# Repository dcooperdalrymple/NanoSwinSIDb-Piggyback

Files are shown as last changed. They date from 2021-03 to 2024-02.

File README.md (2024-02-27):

# NanoSwinSIDb-Piggyback

Have a faulty 6581/8580 SID chip and need a replacement? The Nano SwinSIDb is a great (though I will admit, not best) choice, but it has one fatal flaw: lack of paddle support. Using this revision on the original Nano SwinSIDb design, you can "piggyback" your original SID chip with a faulty audio circuit and use some of it's secondary functions to add back in support for reading analog paddle inputs, external audio input, and random number generator while synthesizing music using the tried-and-true Nano SwinSIDb circuit.



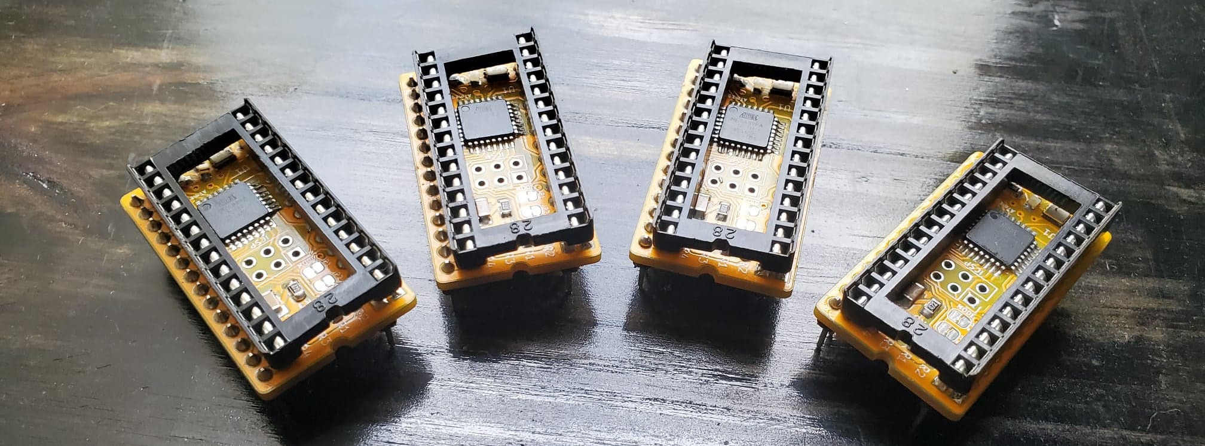
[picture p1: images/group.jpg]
Group of Nano SwinSIDb Piggybacks


## Building
The majority of the components are small SMD parts, but almost all of them can be hand-soldered with a steady hand. The only component that must be soldered using solder paste and a rework station is the active clock chip in a 3.2mm x 2.5mm package. Ensure you double check that no pads are bridged before soldering on the last part, the DIP-28 socket for the SID, because it will cover up a part of the board.

The same jumpers are provided as the original nano SwinSIDb for filter type (MOS6581/MOS8580) and output level (high/low). The jumpers are on by default to use a MOS6581 filter and have high output. You can cut them using an exacto knife to change the settings.

I use PCBWay to manufacture my boards, and all of the necessary files are provided that will be compatible with their services.

<p float="left">
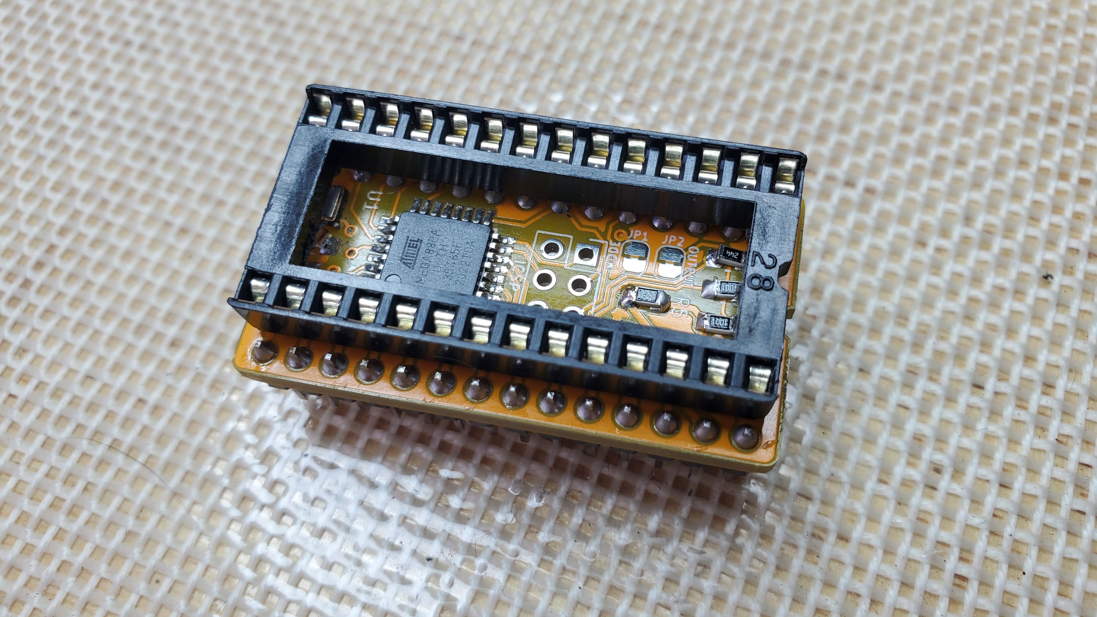
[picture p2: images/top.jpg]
Top of Nano SwinSIDb Piggyback

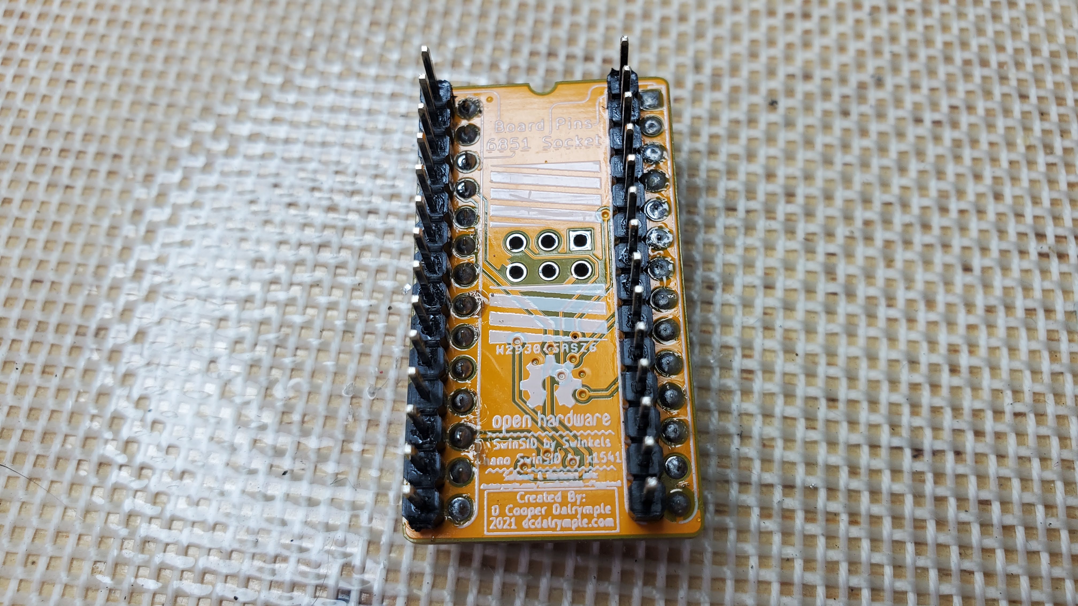
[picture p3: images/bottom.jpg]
Bottom of Nano SwinSIDb Piggyback

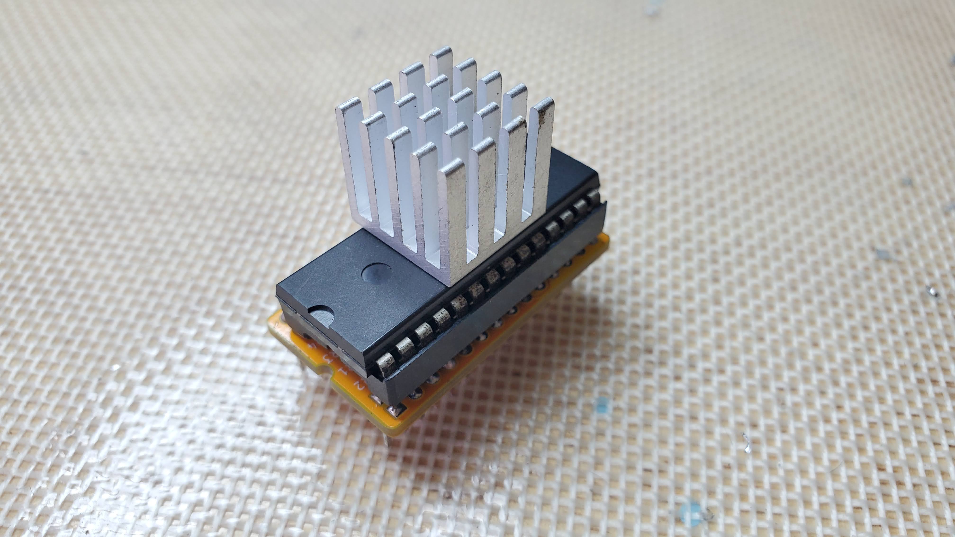
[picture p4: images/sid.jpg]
Nano SwinSIDb Piggyback with MOS6581 on Top

</p>

## Programming Firmware
A standard 6-Pin AVR ICSP header is provided on this board layout unlike the original Nano SwinSIDb. You shouldn't have to solder on a male pin header to program the board. Instead, I use a simple 6-pin cable from my programmer with a male end on it and hold it in place while flashing the chip.

Use the command `make flash` within the firmware directory to flash the copy of the SwinSID firmware with the ['Lazy' fix by Code Killer](http://www.forum64.de/index.php?thread/56605-nano-swinsid-upgrades-paddles-etc/&pageNo=2). Follow this by `make fuse` to ensure that the chip is configured correctly. The makefile utilizes avrdude with an Arduino ISP programmer on port `/dev/ttyACM0` _(linux environment)_. If this configuration doesn't work for you, either modify the Makefile or use your own flash programming environment to flash the provided firmware hex file or any other SwinSID compatible firmware.

## Additional Information
More information about building and programming your own board can be found at [tolaemon.com/nss](http://www.tolaemon.com/nss/). Most of the same principles should apply just with a few different parts. If you'd like to purchase one of these pre-built, I may have some available on my website, [dcdalrymple.com/NanoSwinSIDb-Piggyback/](https://dcdalrymple.com/NanoSwinSIDb-Piggyback/).

## Resources
- [SwinSID Analog Controller Hack](https://ilesj.wordpress.com/2014/07/24/swinsid-analog-controller-hack/)
- [nano SwinSIDb Tutorial](http://www.tolaemon.com/nss/)

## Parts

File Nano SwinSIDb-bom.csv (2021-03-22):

Source | /home/ogrecooper/repos/NanoSwinSIDb-Piggyback/Nano SwinSIDb.sch
Kicad Rev | Eeschema 5.1.9+dfsg1-1
Generated Date | Thu 04 Mar 2021 03:28:03 PM CST
Title | Not Set
Company | Not Set
Revision | Not Set
Date Issue | Not Set
Reference | Value | Library | Library Ref
U1 | ATmega88PA-AU | MCU_Microchip_ATmega | ATmega88PA-AU
JP1 | ModeSelect | Jumper | SolderJumper_2_Bridged
D1 | Yellow | Device | LED
J5 | 6PinConnector | Connector | Conn_01x06_Female
C1 | 100nF | Device | CP
X1 | ECS-3225MV | Oscillator | ECS-2520MV-xxx-xx
R6 | 330 | Device | R_Small
TP1 | TestPoint | Connector | TestPoint
TP2 | TestPoint | Connector | TestPoint
TP3 | TestPoint | Connector | TestPoint
R1 | 1k | Device | R_Small
R2 | 240k | Device | R_Small
R4 | 2.2k | Device | R_Small
R5 | 4.7k | Device | R_Small
R3 | 1k | Device | R_Small
JP2 | OutputVoltage | Jumper | SolderJumper_2_Bridged
U3 | 6581 Socket | Nano-SwinSIDb-rescue | 6581-65xx
U2 | 6581 Pins | Nano-SwinSIDb-rescue | 6581-65xx

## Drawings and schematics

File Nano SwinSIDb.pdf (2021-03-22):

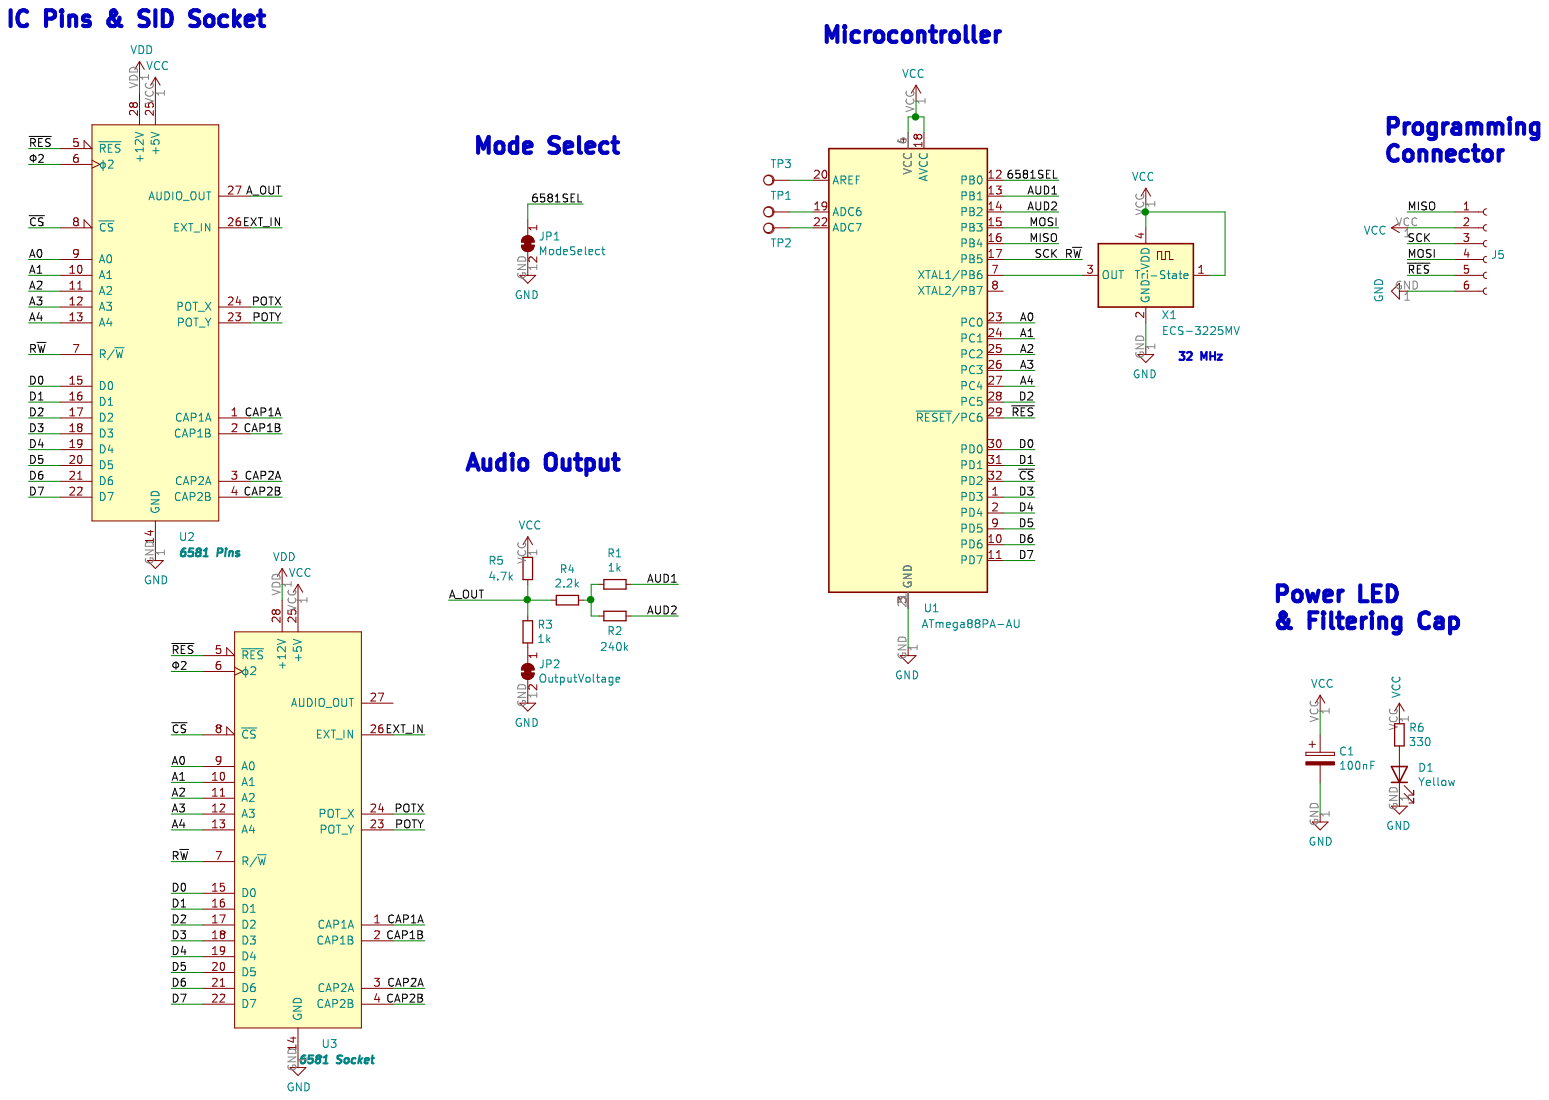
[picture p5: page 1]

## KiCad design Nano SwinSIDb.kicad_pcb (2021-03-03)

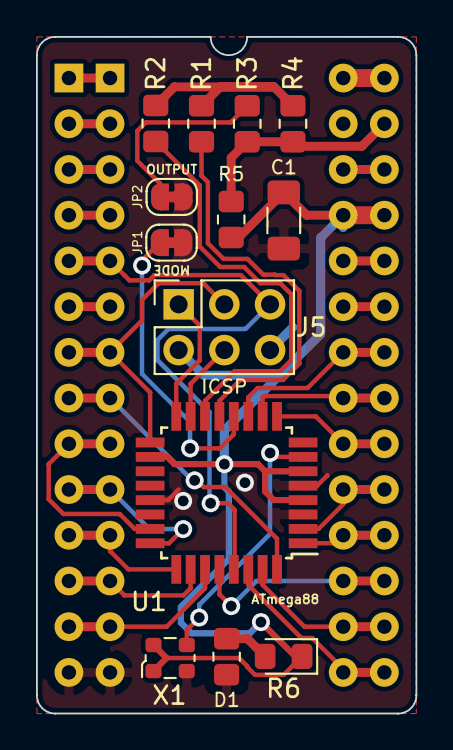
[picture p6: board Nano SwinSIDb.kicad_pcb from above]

Board: 2 copper layers, 21.1 x 37.6 mm, 15 parts (0 on the bottom side), 37 nets.

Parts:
C1: 100nF; C_1206_3216Metric_Pad1.33x1.80mm_HandSolder
D1: Yellow; R_0805_2012Metric_Pad1.20x1.40mm_HandSolder
J5: 6PinConnector; PinSocket_2x03_P2.54mm_Vertical
JP1: ModeSelect; SolderJumper-2_P1.3mm_Bridged_RoundedPad1.0x1.5mm
JP2: OutputVoltage; SolderJumper-2_P1.3mm_Bridged_RoundedPad1.0x1.5mm
R1, R3: 1k; R_0805_2012Metric_Pad1.20x1.40mm_HandSolder
R2: 240k; R_0805_2012Metric_Pad1.20x1.40mm_HandSolder
R4: 2.2k; R_0805_2012Metric_Pad1.20x1.40mm_HandSolder
R5: 4.7k; R_0805_2012Metric_Pad1.20x1.40mm_HandSolder
R6: 330; LED_0805_2012Metric_Pad1.15x1.40mm_HandSolder
U1: ATmega88PA-AU; TQFP-32_7x7mm_P0.8mm
U2: 6581 Pins; DIP-28_W15.24mm
U3: 6581 Socket; DIP-28_W15.24mm_Socket
X1: ECS-3225MV; Oscillator_SMD_ECS_2520MV-xxx-xx-4Pin_2.5x2.0mm

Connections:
/6581SEL: JP1.1, U1.12
/A0: U1.23, U2.9, U3.9
/A1: U1.24, U2.10, U3.10
/A2: U1.25, U2.11, U3.11
/A3: U1.26, U2.12, U3.12
/A4: U1.27, U2.13, U3.13
/AUD1: R1.1, U1.13
/AUD2: R2.2, U1.14
/A_OUT: R3.1, R4.2, R5.2, U2.27
/CAP1A: U2.1, U3.1
/CAP1B: U2.2, U3.2
/CAP2A: U2.3, U3.3
/CAP2B: U2.4, U3.4
/D0: U1.30, U2.15, U3.15
/D1: U1.31, U2.16, U3.16
/D2: U1.28, U2.17, U3.17
/D3: U1.1, U2.18, U3.18
/D4: U1.2, U2.19, U3.19
/D5: U1.9, U2.20, U3.20
/D6: U1.10, U2.21, U3.21
/D7: U1.11, U2.22, U3.22
/EXT_IN: U2.26, U3.26
/MISO: J5.1, U1.16
/MOSI: J5.4, U1.15
/POTX: U2.24, U3.24
/POTY: U2.23, U3.23
/R~W~: J5.3, U1.17, U2.7, U3.7
/~CS~: U1.32, U2.8, U3.8
/~RES~: J5.5, U1.29, U2.5, U3.5
/Φ2: U2.6, U3.6
GND: C1.2, D1.1, J5.6, JP1.2, JP2.2, U1.3, U1.5, U1.21, U2.14, U3.14, X1.2
unnamed: D1.2, R6.2
unnamed: JP2.1, R3.2
unnamed: R1.2, R2.1, R4.1
unnamed: U1.7, X1.3
VCC: C1.1, J5.2, R5.1, R6.1, U1.4, U1.6, U1.18, U2.25, U3.25, X1.1, X1.4
VDD: U2.28, U3.28

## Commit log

2021-02-24 Initial KiCad design work.
    [Nano SwinSIDb.kicad_pcb, Nano SwinSIDb.sch]
2021-02-24 First draft of PCB. Needs silkscreen work.
    [Nano SwinSIDb.kicad_pcb]
2021-03-03 Completed pcb design and gerber files for manufacture.
    [Nano SwinSIDb-B_Cu.gbl, Nano SwinSIDb-B_Mask.gbs, Nano SwinSIDb-B_Paste.gbp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]
2021-03-12 Firmware added for use with Arduino ISP.
2021-03-22 Added images and updated readme.
    [Nano SwinSIDb-bom.csv]
